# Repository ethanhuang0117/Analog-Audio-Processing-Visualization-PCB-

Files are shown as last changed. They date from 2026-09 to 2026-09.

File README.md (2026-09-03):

# Analog Audio Processing & Visualization PCB

A custom analog audio spectrum analyzer PCB that processes microphone audio across 8 frequency bands and displays signal intensity using 4-level LED indicators.

<p align="center">
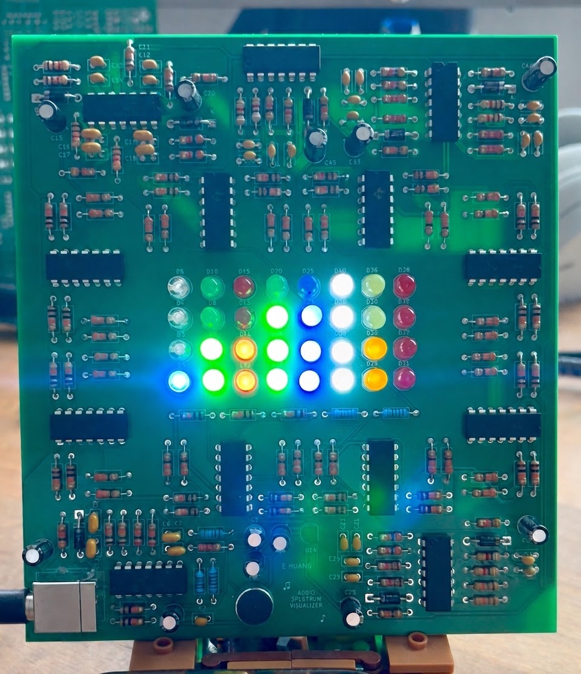
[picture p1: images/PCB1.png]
  
</p>

### Demo

[Download and Watch the PCB Demo](images/demo.mp4)

## Overview

The system captures audio through an electret microphone, amplifies the signal, separates it into 8 frequency bands using active filters, and displays the signal intensity through LED indicators.

**System Chain:**

Microphone → Preamp → 8-Band Filters → Envelope Detection → Comparators → LED Visualization

## Features

- 8 frequency bands spanning approximately 80 Hz – 10 kHz
- Cascaded Sallen-Key active filters for improved frequency separation
- Microphone preamplification for low-level audio signals
- Envelope detection to convert AC audio signals into DC levels
- 4-level LED intensity indication for each frequency band using comparators
- USB 5 V single-supply
- Custom PCB designed and assembled in KiCad

## Frequency Bands

| Band | Centre Frequency |
|---|---:|
| 1 | 80 Hz |
| 2 | 160 Hz |
| 3 | 320 Hz |
| 4 | 640 Hz |
| 5 | 1.25 kHz |
| 6 | 2.5 kHz |
| 7 | 5 kHz |
| 8 | 10 kHz |

## Filter Design

The initial design used passive filters, but were redesigned using cascaded Sallen-Key active filters to achieve greater roll-off and band separation.

<p align="center">
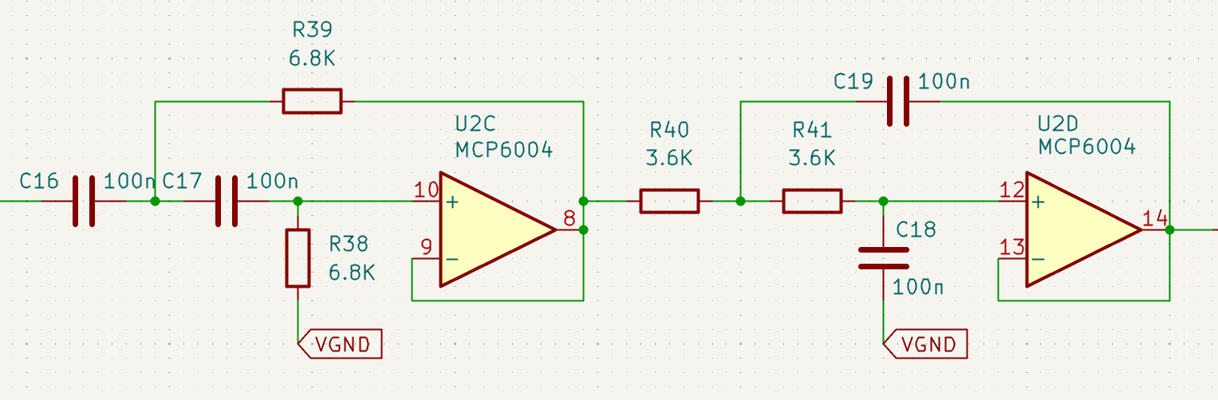
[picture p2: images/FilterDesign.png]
  
</p>

### Sallen-Key Bandpass Filter Calculations

Each frequency band consists of a cascaded 2nd order Sallen-Key High Pass Filter (HPF) and Low Pass Filter (LPF).

**Assumptions:**
- $R_1 = R_2 = R$
- $C_1 = C_2 = C$
- $C = 100\text{nF}$ (Bands 1-4), $C = 10\text{nF}$ (Bands 5-8)

The cutoff frequencies are spaced by $\sqrt{2}$ from the centre frequency.

$$f_H = f_0 \times \sqrt{2}$$

$$f_L = \frac{f_0}{\sqrt{2}}$$

The general Sallen-Key cutoff frequency formula before simplification is:

$$f = \frac{1}{2\pi\sqrt{R_1 R_2 C_1 C_2}}$$

Applying the assumptions $R_1 = R_2 = R$ and $C_1 = C_2 = C$, this simplifies to:

$$f = \frac{1}{2\pi RC}$$

Rearranging for $R$:

$$R = \frac{1}{2\pi f C}$$

---

### Band 4 Example (Centre frequency: 640Hz)

**Step 1: Calculate HPF cutoff frequency**

$$f_L = \frac{f_0}{\sqrt{2}} = \frac{640}{\sqrt{2}} = 453\text{Hz}$$

**Step 2: Calculate LPF cutoff frequency**

$$f_H = f_0 \times \sqrt{2} = 640 \times \sqrt{2} = 905\text{Hz}$$

**Step 3: Calculate HPF resistor value ($C = 100\text{nF}$)**

$$R_{HPF} = \frac{1}{2\pi \times 453 \times 100 \times 10^{-9}} = 3513\Omega \approx 3.6\text{k}\Omega$$

**Step 4: Calculate LPF resistor value ($C = 100\text{nF}$)**

$$R_{LPF} = \frac{1}{2\pi \times 905 \times 100 \times 10^{-9}} = 1759\Omega \approx 1.8\text{k}\Omega$$

---

### Filter Band Summary

| Band | Centre Frequency | C | HPF Cutoff | HPF R | LPF Cutoff | LPF R |
|---|---|---|---|---|---|---|
| 1 | 80Hz | 100nF | 56.6Hz | 27kΩ | 113Hz | 15kΩ |
| 2 | 160Hz | 100nF | 113Hz | 15kΩ | 226Hz | 6.8kΩ |
| 3 | 320Hz | 100nF | 226Hz | 6.8kΩ | 453Hz | 3.6kΩ |
| 4 | 640Hz | 100nF | 453Hz | 3.6kΩ | 905Hz | 1.8kΩ |
| 5 | 1.25kHz | 10nF | 884Hz | 18kΩ | 1.77kHz | 9.1kΩ |
| 6 | 2.5kHz | 10nF | 1.77kHz | 9.1kΩ | 3.54kHz | 4.7kΩ |
| 7 | 5kHz | 10nF | 3.54kHz | 4.7kΩ | 7.07kHz | 2.2kΩ |
| 8 | 10kHz | 10nF | 7.07kHz | 2.2kΩ | 14.1kHz | 1.1kΩ |

## Circuit Design

### Power

The circuit operates from a 5 V USB supply. Since audio signals oscillate about a center point, a virtual ground of 2.5V is used to allow the analog signal stages to operate from a single supply.

<p align="center">
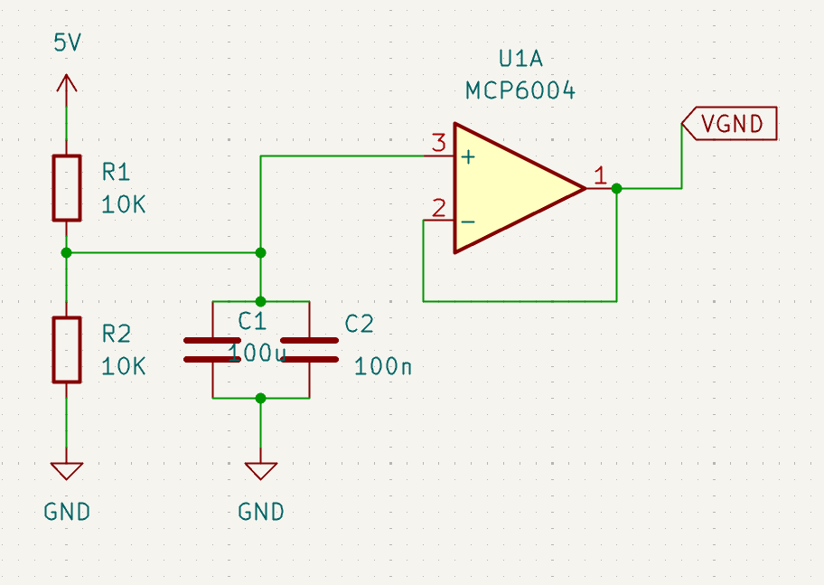
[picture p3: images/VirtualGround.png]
  
</p>

### Microphone & Preamplifier

A CMA-4544PF-W electret microphone captures the incoming audio signal, which is amplified using an MCP6004 op-amp to provide a suitable signal level for the filter stages.

The CMA-4544PF-W was chosen because its frequency response of 20Hz-20kHz covers the full audio spectrum.

<p align="center">
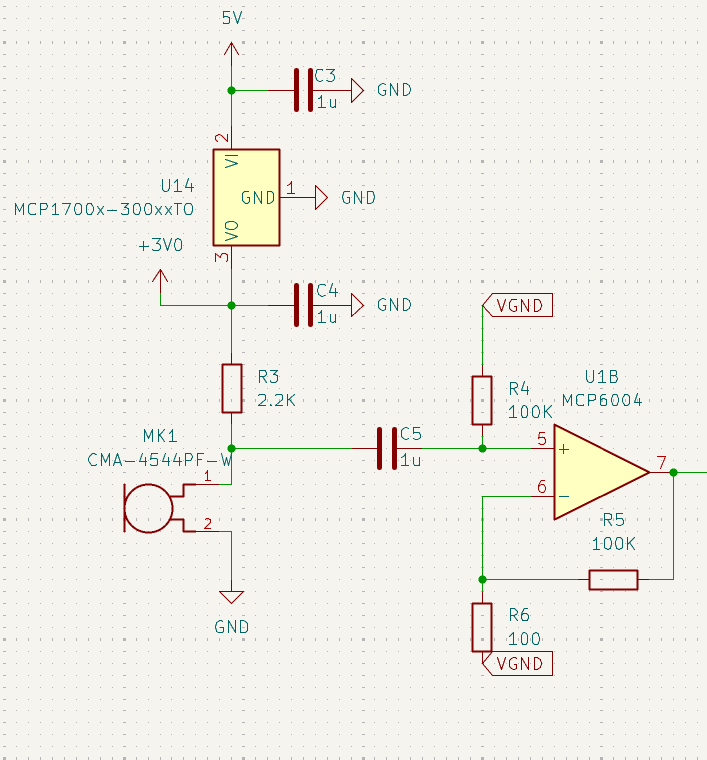
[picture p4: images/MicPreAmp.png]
  
</p>

### Envelope Detection

Each filtered signal passes through an envelope detector to convert the AC waveform into a varying DC voltage proportional to its amplitude.

<p align="center">
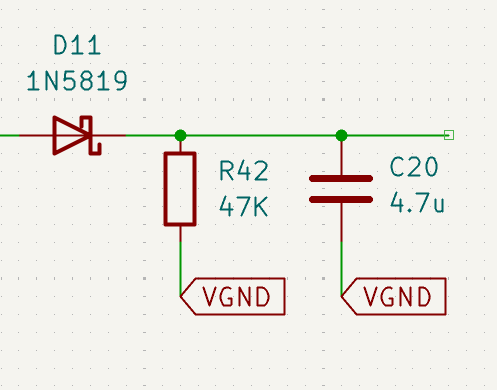
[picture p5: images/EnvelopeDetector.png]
  
</p>

The RC time constant determines the decay time of the envelope:

$$\tau = R \times C = 47\text{k}\Omega \times 4.7\mu\text{F} = 221\text{ms}$$

This gives a smooth, natural decay that visually tracks the music without flickering too fast or responding too sluggishly.

### Comparator & LED Stage

Comparator circuits divide each detected signal into four amplitude thresholds. The resulting outputs drive four LEDs per frequency band to provide a 4-level visualization of audio intensity.

## Prototyping & Testing

Individual circuit stages were first tested on breadboards and simulated in Multisim before PCB fabrication.

<p align="center">
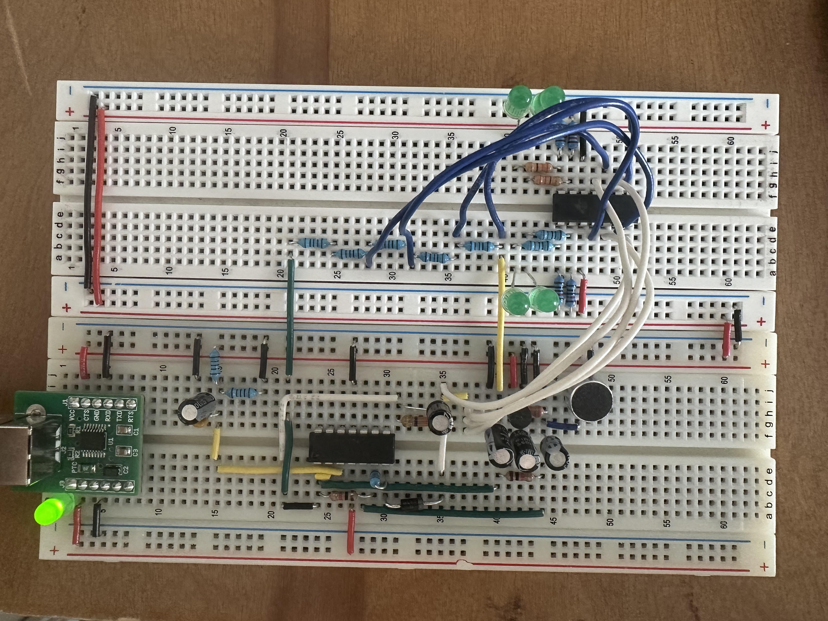
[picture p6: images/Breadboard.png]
  
</p>

This iterative testing helped identify design issues before fabrication and reduced the need for PCB rework.

## PCB Design

The validated circuit was translated into a custom PCB using KiCad, with component placement, routing, and ground pours optimized for a compact and reliable layout.

<p align="center">
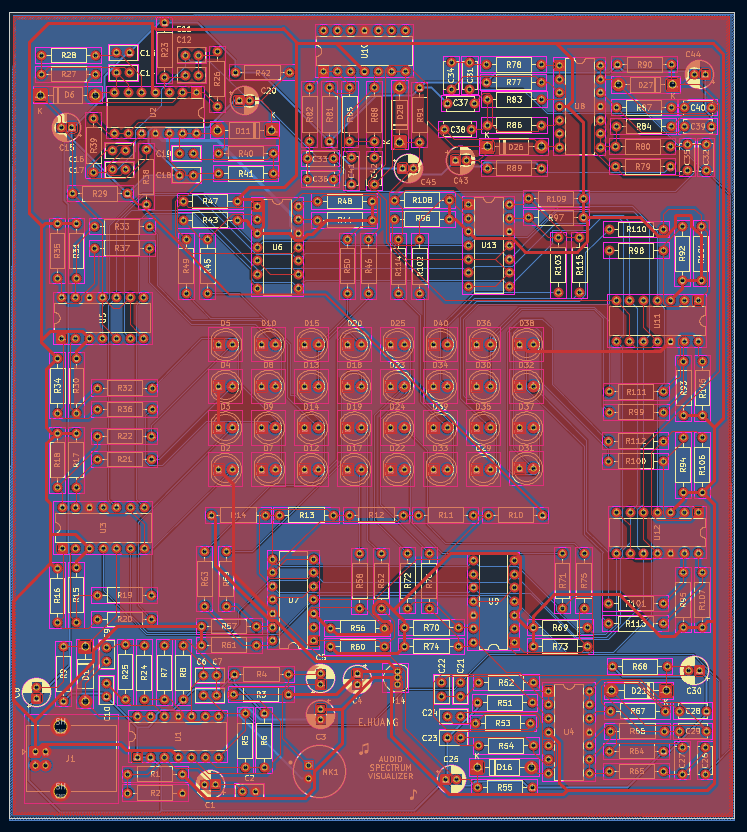
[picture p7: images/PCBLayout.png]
  
</p>

### 3D PCB View

<p align="center">
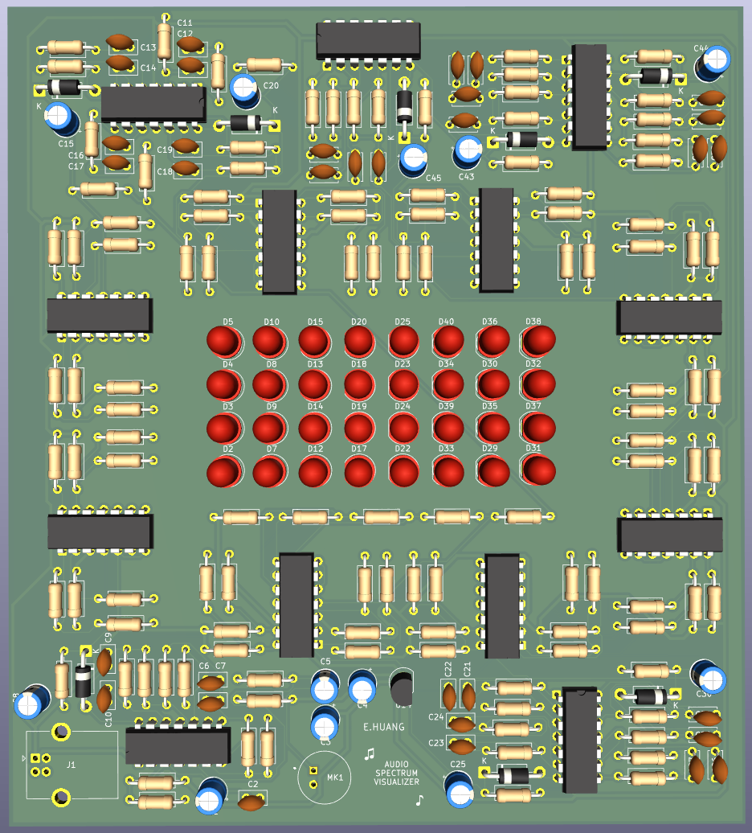
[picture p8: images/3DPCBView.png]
  
</p>

### Schematic

[View Full Schematic (PDF)](Schematic.pdf)

## Results

The completed PCB successfully processes audio through the 8 frequency bands and provides visual feedback through the LED array.

<p align="center">
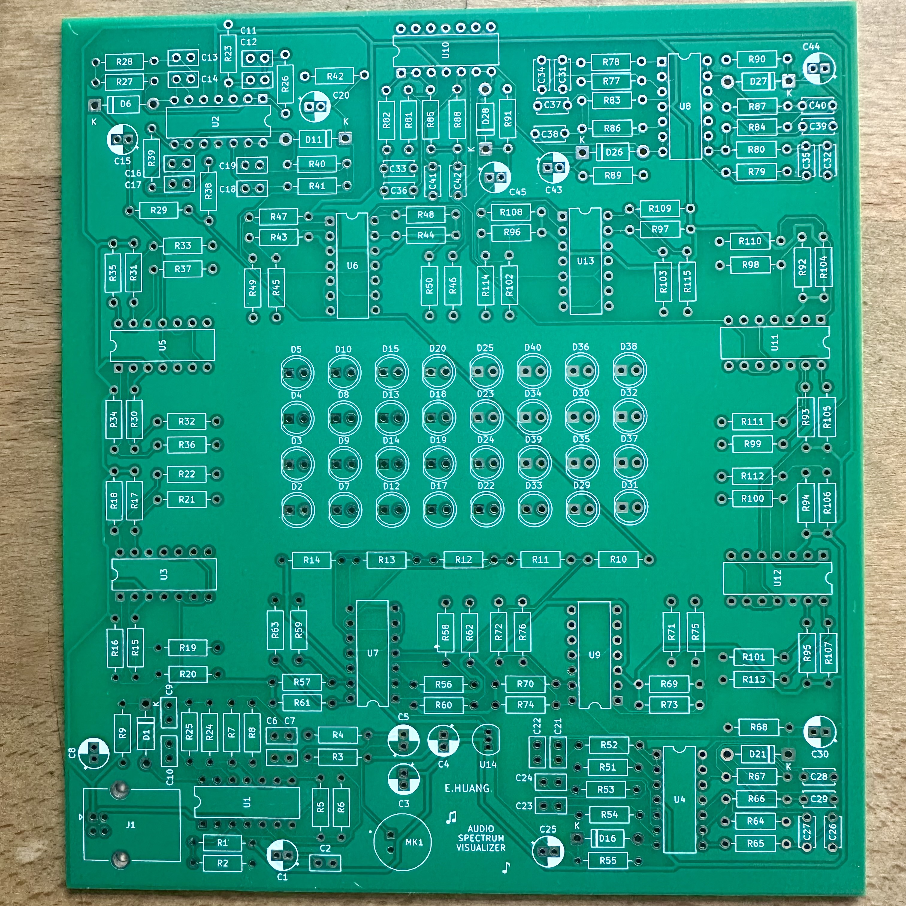
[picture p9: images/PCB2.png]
  
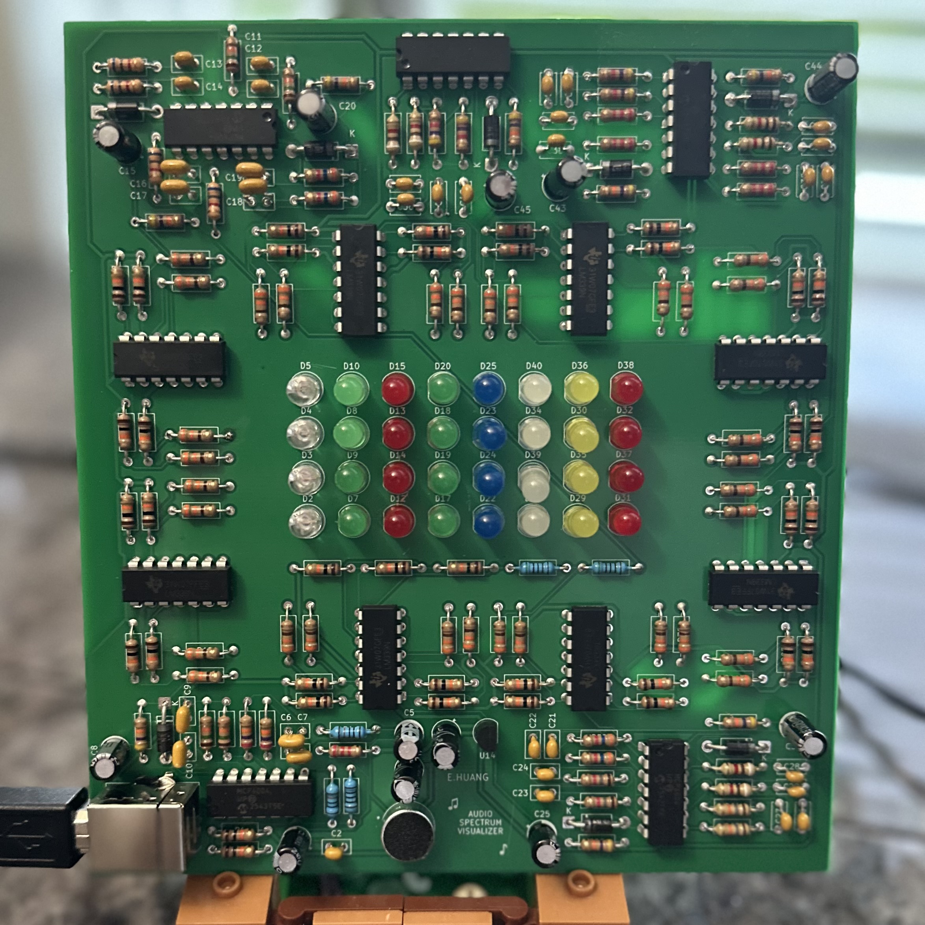
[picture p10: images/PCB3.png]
  
</p>

## Design Challenges & Iterations

### Passive → Active Filter Redesign

The original passive filter approach did not provide sufficient frequency separation. Sallen-Key active filters were implemented to improve roll-off and isolation between adjacent bands.

### Gain Optimization

The preamplifier gain was iteratively adjusted during breadboard testing to provide sufficient signal amplitude without excessive amplification of noise.

### Single-Supply Operation

Because the circuit operates from a 5 V USB supply, a virtual ground was implemented to allow the op-amp stages to process audio signals within the available supply range.

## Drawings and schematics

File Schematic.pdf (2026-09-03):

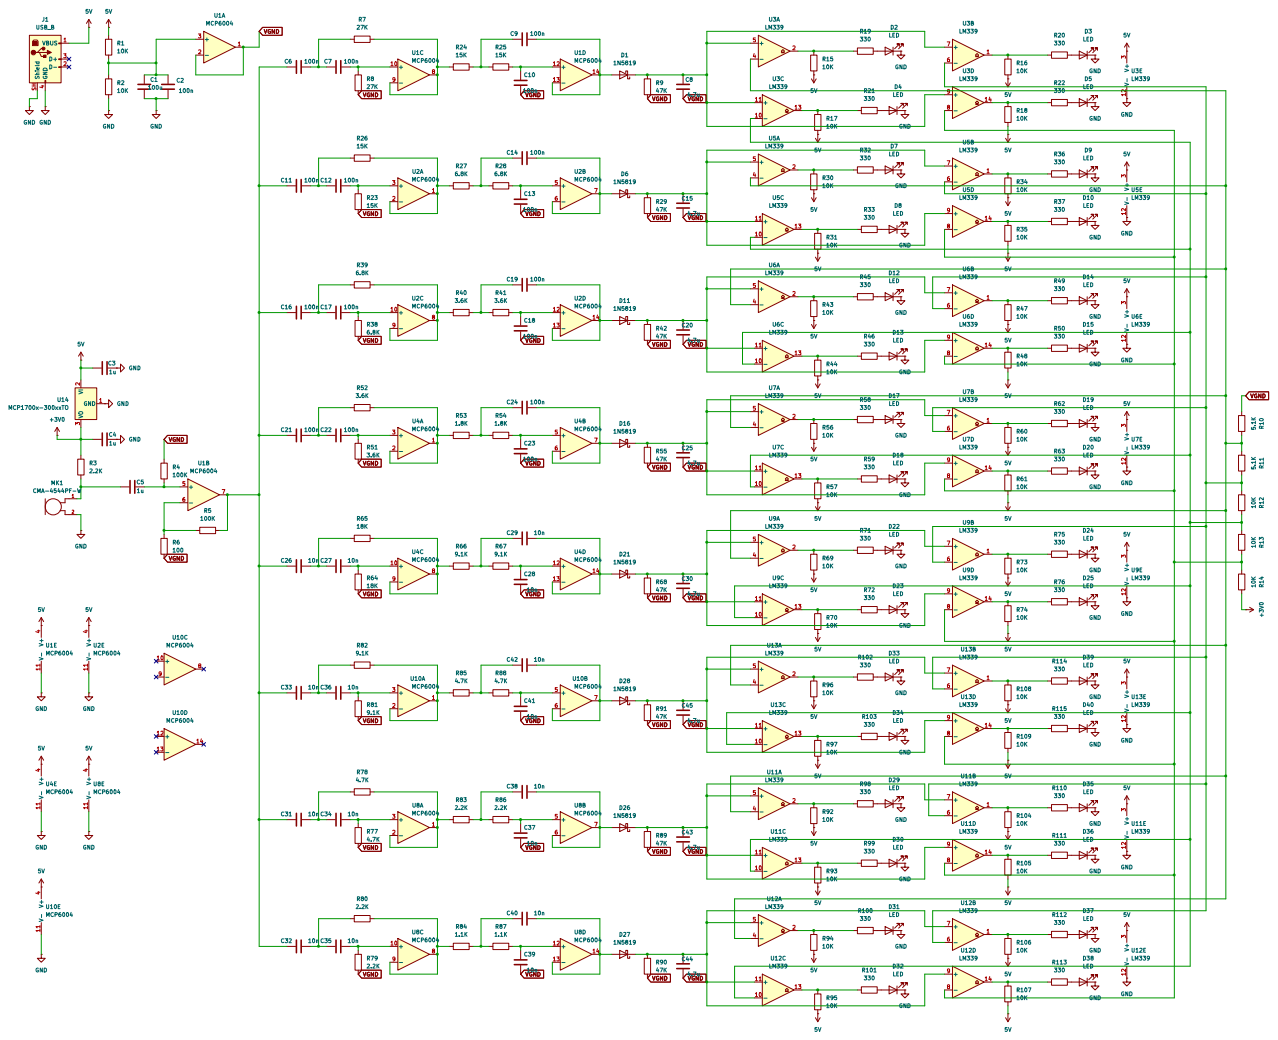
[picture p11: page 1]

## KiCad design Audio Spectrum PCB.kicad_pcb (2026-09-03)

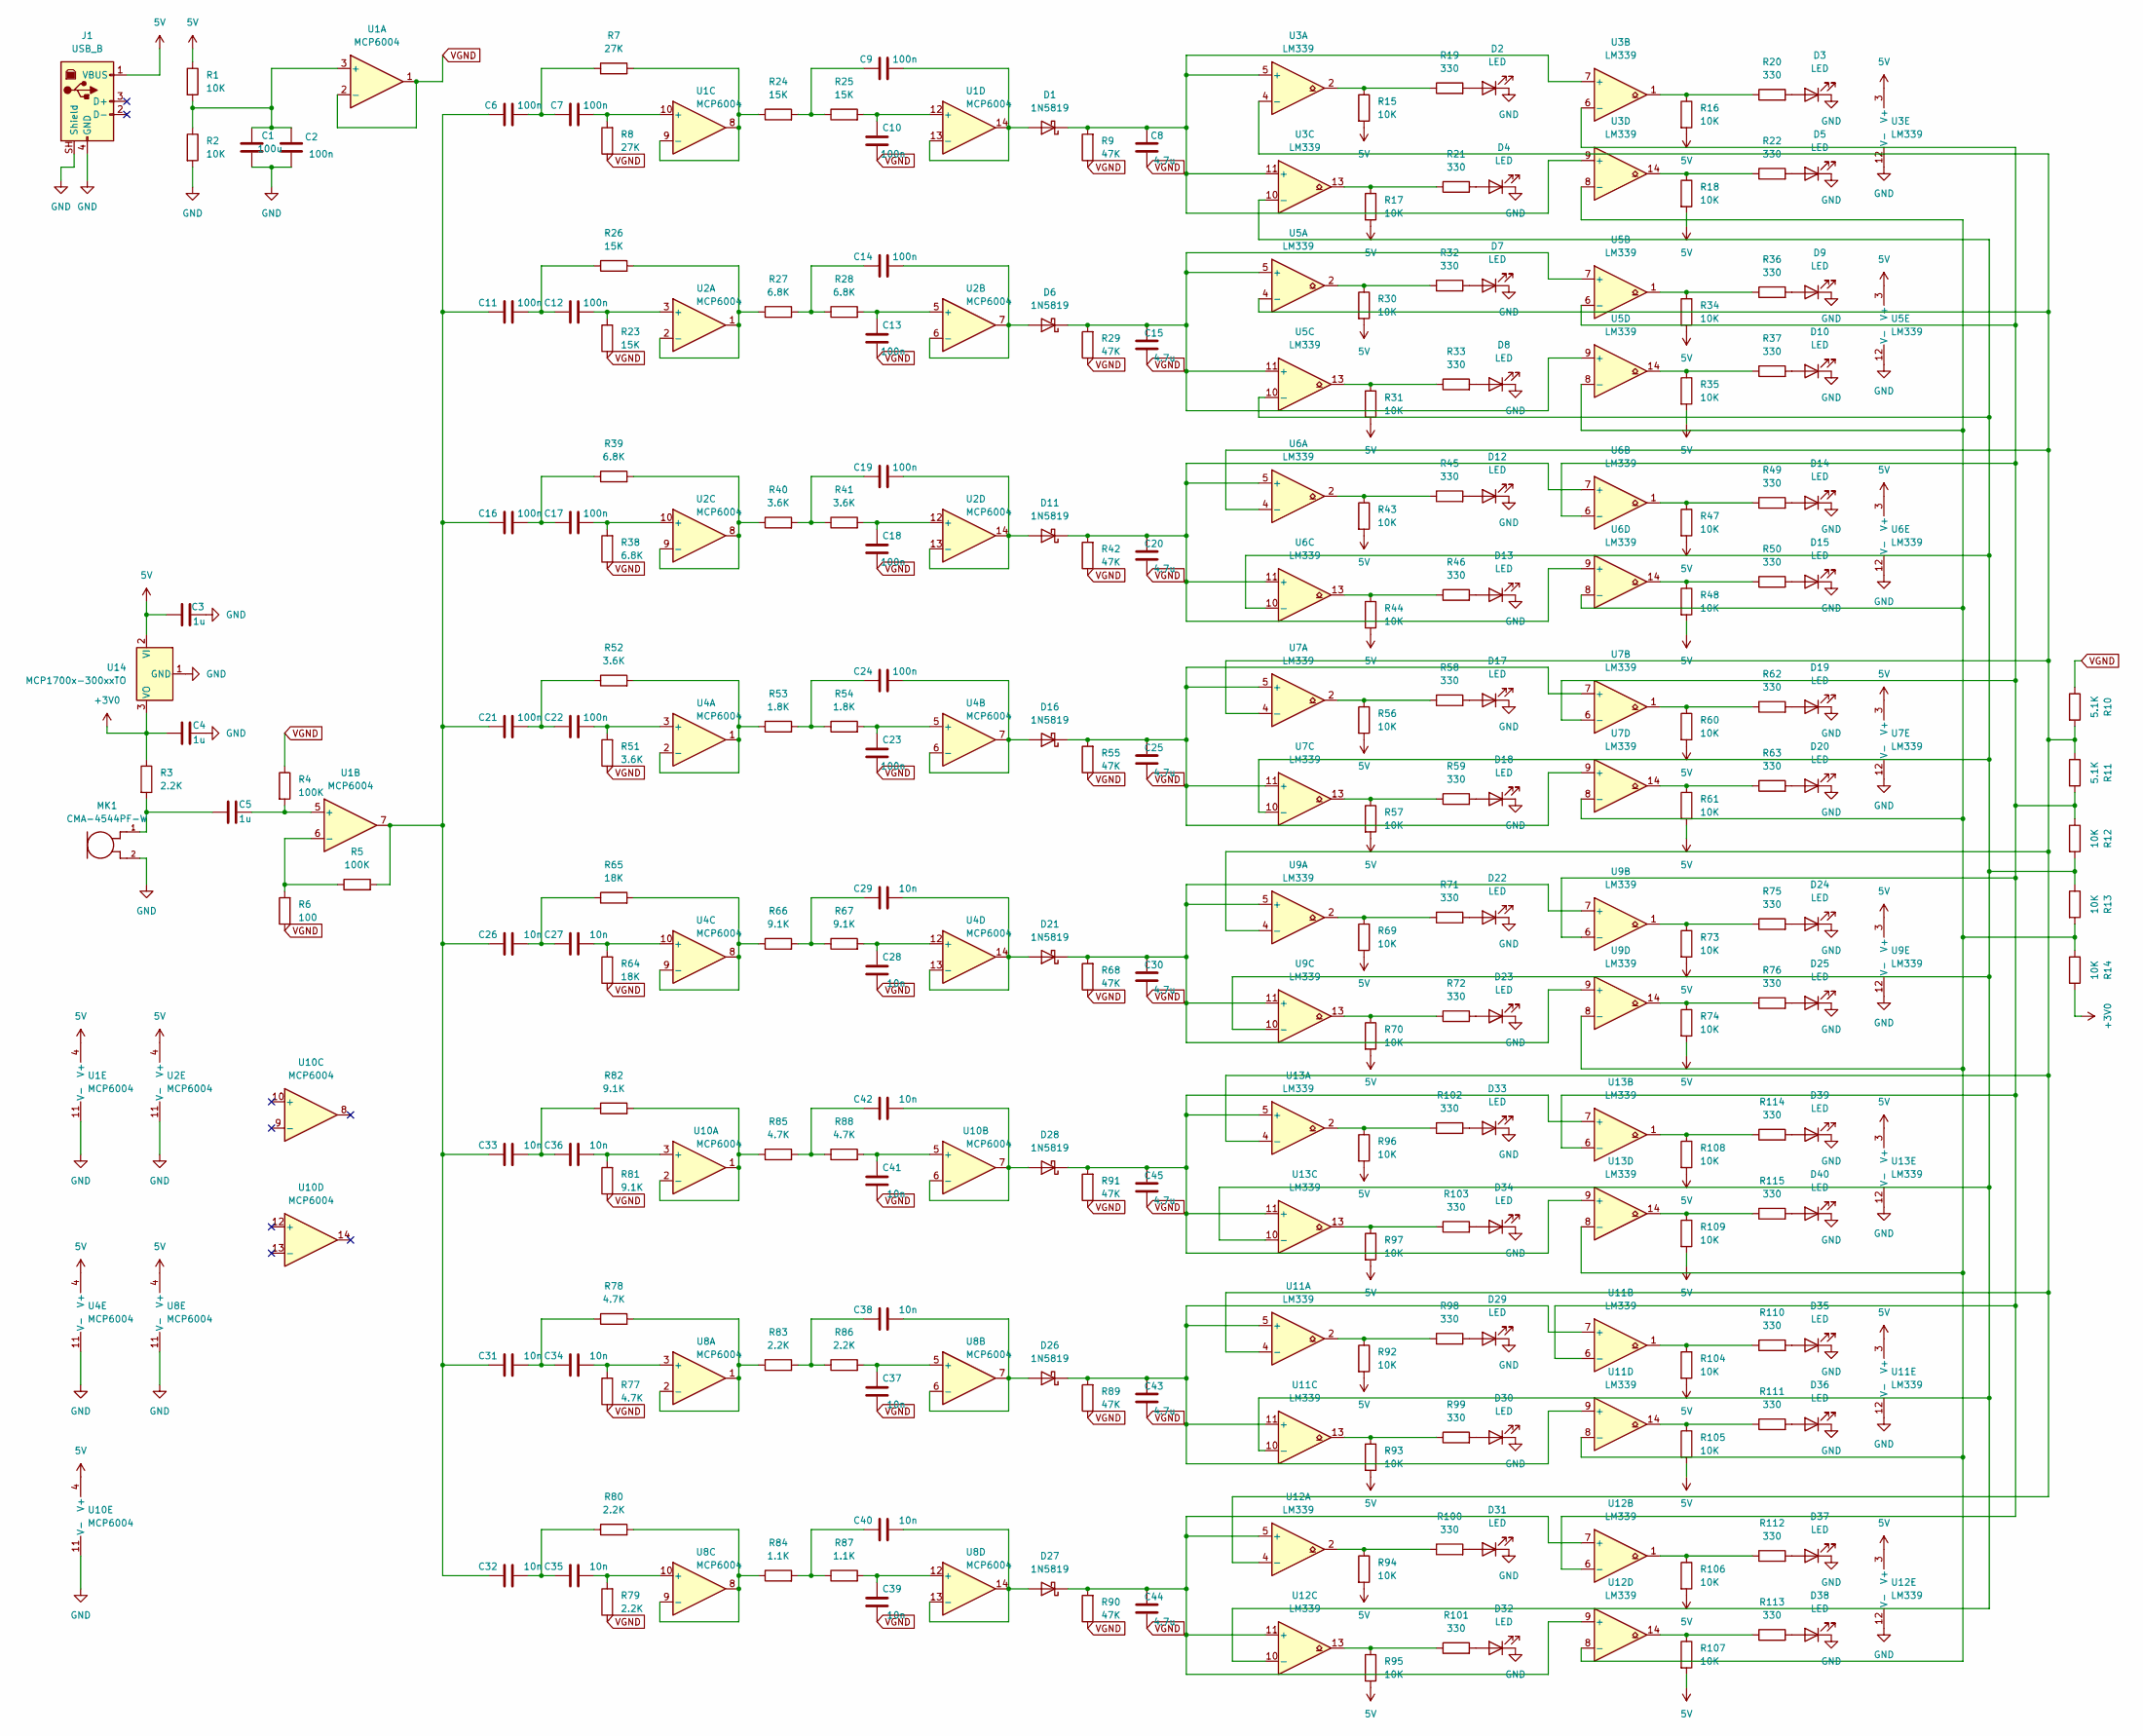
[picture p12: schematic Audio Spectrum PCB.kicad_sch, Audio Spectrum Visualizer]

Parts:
C1: 100u; CP_Radial_D5.0mm_P2.00mm
C2, C6, C7, C9, C10, C11, C12, C13, C14, C16, C17, C18, C19, C21, C22, C23, C24: 100n; C_Disc_D5.0mm_W2.5mm_P2.50mm
C3, C4, C5: 1u; CP_Radial_D5.0mm_P2.00mm
C8, C15, C20, C25, C30, C43, C44, C45: 4.7u; CP_Radial_D5.0mm_P2.00mm
C26, C27, C28, C29, C31, C32, C33, C34, C35, C36, C37, C38, C39, C40, C41, C42: 10n; C_Disc_D5.0mm_W2.5mm_P5.00mm
D1, D6, D11, D16, D21, D26, D27, D28: 1N5819; D_DO-41_SOD81_P10.16mm_Horizontal
D2, D3, D4, D5, D7, D8, D9, D10, D12, D13, D14, D15, D17, D18, D19, D20, D22, D23, D24, D25, D29, D30, D31, D32, D33, D34, D35, D36, D37, D38, D39, D40: LED; LED_D5.0mm
J1: USB_B; USB_B_OST_USB-B1HSxx_Horizontal
MK1: CMA-4544PF-W; MIC_CMA-4544PF-W
R1, R2, R12, R13, R14, R15, R16, R17, R18, R30, R31, R34, R35, R43, R44, R47, R48, R56, R57, R60, R61, R69, R70, R73, R74, R92, R93, R94, R95, R96, R97, R104, R105, R106, R107, R108, R109: 10K; R_Axial_DIN0207_L6.3mm_D2.5mm_P10.16mm_Horizontal
R3, R79, R80, R83, R86: 2.2K; R_Axial_DIN0207_L6.3mm_D2.5mm_P10.16mm_Horizontal
R4, R5: 100K; R_Axial_DIN0207_L6.3mm_D2.5mm_P10.16mm_Horizontal
R6: 100; R_Axial_DIN0207_L6.3mm_D2.5mm_P10.16mm_Horizontal
R7, R8: 27K; R_Axial_DIN0207_L6.3mm_D2.5mm_P10.16mm_Horizontal
R9, R29, R42, R55, R68, R89, R90, R91: 47K; R_Axial_DIN0207_L6.3mm_D2.5mm_P10.16mm_Horizontal
R10, R11: 5.1K; R_Axial_DIN0207_L6.3mm_D2.5mm_P10.16mm_Horizontal
R19, R20, R21, R22, R32, R33, R36, R37, R45, R46, R49, R50, R58, R59, R62, R63, R71, R72, R75, R76, R98, R99, R100, R101, R102, R103, R110, R111, R112, R113, R114, R115: 330; R_Axial_DIN0207_L6.3mm_D2.5mm_P10.16mm_Horizontal
R23, R24, R25, R26: 15K; R_Axial_DIN0207_L6.3mm_D2.5mm_P10.16mm_Horizontal
R27, R28, R38, R39: 6.8K; R_Axial_DIN0207_L6.3mm_D2.5mm_P10.16mm_Horizontal
R40, R41, R51, R52: 3.6K; R_Axial_DIN0207_L6.3mm_D2.5mm_P10.16mm_Horizontal
R53, R54: 1.8K; R_Axial_DIN0207_L6.3mm_D2.5mm_P10.16mm_Horizontal
R64, R65: 18K; R_Axial_DIN0207_L6.3mm_D2.5mm_P10.16mm_Horizontal
R66, R67, R81, R82: 9.1K; R_Axial_DIN0207_L6.3mm_D2.5mm_P10.16mm_Horizontal
R77, R78, R85, R88: 4.7K; R_Axial_DIN0207_L6.3mm_D2.5mm_P10.16mm_Horizontal
R84, R87: 1.1K; R_Axial_DIN0207_L6.3mm_D2.5mm_P10.16mm_Horizontal
U1, U2, U4, U8, U10: MCP6004; DIP-14_W7.62mm
U3, U5, U6, U7, U9, U11, U12, U13: LM339; DIP-14_W7.62mm
U14: MCP1700x-300xxTO; TO-92_Inline

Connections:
5V: C3.1, J1.1 (VBUS), R1.1, R15.2, R16.2, R17.2, R18.2, R30.2, R31.2, R34.2, R35.2, R43.2, R44.2, R47.2, R48.2, R56.2, R57.2, R60.2, R61.2, R69.2, R70.2, R73.2, R74.2, R92.2, R93.2, R94.2, R95.2, R96.2, R97.2, R104.2, R105.2, R106.2, R107.2, R108.2, R109.2, U1.4 (V+), U2.4 (V+), U3.3 (V+), U4.4 (V+), U5.3 (V+), U6.3 (V+), U7.3 (V+), U8.4 (V+), U9.3 (V+), U10.4 (V+), U11.3 (V+), U12.3 (V+), U13.3 (V+), U14.2 (VI)
+3V0: C4.1, R3.1, R14.2, U14.3 (VO)
GND: C1.2, C2.2, C3.2, C4.2, D2.1 (K), D3.1 (K), D4.1 (K), D5.1 (K), D7.1 (K), D8.1 (K), D9.1 (K), D10.1 (K), D12.1 (K), D13.1 (K), D14.1 (K), D15.1 (K), D17.1 (K), D18.1 (K), D19.1 (K), D20.1 (K), D22.1 (K), D23.1 (K), D24.1 (K), D25.1 (K), D29.1 (K), D30.1 (K), D31.1 (K), D32.1 (K), D33.1 (K), D34.1 (K), D35.1 (K), D36.1 (K), D37.1 (K), D38.1 (K), D39.1 (K), D40.1 (K), J1.4 (GND), J1.SH (Shield), MK1.2, R2.2, U1.11 (V-), U2.11 (V-), U3.12 (V-), U4.11 (V-), U5.12 (V-), U6.12 (V-), U7.12 (V-), U8.11 (V-), U9.12 (V-), U10.11 (V-), U11.12 (V-), U12.12 (V-), U13.12 (V-), U14.1 (GND)
unnamed: C5.1, MK1.1, R3.2
unnamed: C6.2, C7.1, R7.1
unnamed: C9.1, R24.2, R25.1
unnamed: C6.1, C11.1, C16.1, C21.1, C26.1, C31.1, C32.1, C33.1, R5.2, U1.7
unnamed: C11.2, C12.1, R26.1
unnamed: C14.1, R27.2, R28.1
unnamed: C16.2, C17.1, R39.1
unnamed: C19.1, R40.2, R41.1
unnamed: C21.2, C22.1, R52.1
unnamed: C24.1, R53.2, R54.1
unnamed: C26.2, C27.1, R65.1
unnamed: C29.1, R66.2, R67.1
unnamed: C31.2, C34.1, R78.1
unnamed: C32.2, C35.1, R80.1
unnamed: C33.2, C36.1, R82.1
unnamed: C38.1, R83.2, R86.1
unnamed: C40.1, R84.2, R87.1
unnamed: C42.1, R85.2, R88.1
unnamed: C9.2, D1.2 (A), U1.13 (-), U1.14
unnamed: C8.2, D1.1 (K), R9.2, U3.5 (+), U3.7 (+), U3.9 (+), U3.11 (+)
unnamed: D2.2 (A), R19.2
unnamed: D3.2 (A), R20.2
unnamed: D4.2 (A), R21.2
unnamed: D5.2 (A), R22.2
unnamed: C14.2, D6.2 (A), U2.6 (-), U2.7
unnamed: C15.2, D6.1 (K), R29.2, U5.5 (+), U5.7 (+), U5.9 (+), U5.11 (+)
unnamed: D7.2 (A), R32.2
unnamed: D8.2 (A), R33.2
unnamed: D9.2 (A), R36.2
unnamed: D10.2 (A), R37.2
unnamed: C19.2, D11.2 (A), U2.13 (-), U2.14
unnamed: C20.2, D11.1 (K), R42.2, U6.5 (+), U6.7 (+), U6.9 (+), U6.11 (+)
unnamed: D12.2 (A), R45.2
unnamed: D13.2 (A), R46.2
unnamed: D14.2 (A), R49.2
unnamed: D15.2 (A), R50.2
unnamed: C24.2, D16.2 (A), U4.6 (-), U4.7
unnamed: C25.2, D16.1 (K), R55.2, U7.5 (+), U7.7 (+), U7.9 (+), U7.11 (+)
unnamed: D17.2 (A), R58.2
unnamed: D18.2 (A), R59.2
unnamed: D19.2 (A), R62.2
unnamed: D20.2 (A), R63.2
unnamed: C29.2, D21.2 (A), U4.13 (-), U4.14
unnamed: C30.2, D21.1 (K), R68.2, U9.5 (+), U9.7 (+), U9.9 (+), U9.11 (+)
unnamed: D22.2 (A), R71.2
unnamed: D23.2 (A), R72.2
unnamed: D24.2 (A), R75.2
unnamed: D25.2 (A), R76.2
unnamed: C38.2, D26.2 (A), U8.6 (-), U8.7
unnamed: C43.2, D26.1 (K), R89.2, U11.5 (+), U11.7 (+), U11.9 (+), U11.11 (+)
unnamed: C40.2, D27.2 (A), U8.13 (-), U8.14
unnamed: C44.2, D27.1 (K), R90.2, U12.5 (+), U12.7 (+), U12.9 (+), U12.11 (+)
unnamed: C42.2, D28.2 (A), U10.6 (-), U10.7
unnamed: C45.2, D28.1 (K), R91.2, U13.5 (+), U13.7 (+), U13.9 (+), U13.11 (+)
unnamed: D29.2 (A), R98.2
unnamed: D30.2 (A), R99.2
unnamed: D31.2 (A), R100.2
unnamed: D32.2 (A), R101.2
unnamed: D33.2 (A), R102.2
unnamed: D34.2 (A), R103.2
unnamed: D35.2 (A), R110.2
unnamed: D36.2 (A), R111.2
unnamed: D37.2 (A), R112.2
unnamed: D38.2 (A), R113.2
unnamed: D39.2 (A), R114.2
unnamed: D40.2 (A), R115.2
unnamed: R15.1, R19.1, U3.2
unnamed: R16.1, R20.1, U3.1
unnamed: R17.1, R21.1, U3.13
unnamed: R18.1, R22.1, U3.14
unnamed: R30.1, R32.1, U5.2
unnamed: R31.1, R33.1, U5.13
unnamed: R34.1, R36.1, U5.1
unnamed: R35.1, R37.1, U5.14
unnamed: R43.1, R45.1, U6.2
unnamed: R44.1, R46.1, U6.13
unnamed: R47.1, R49.1, U6.1
unnamed: R48.1, R50.1, U6.14
unnamed: R56.1, R58.1, U7.2
unnamed: R57.1, R59.1, U7.13
unnamed: R60.1, R62.1, U7.1
unnamed: R61.1, R63.1, U7.14
unnamed: R69.1, R71.1, U9.2
unnamed: R70.1, R72.1, U9.13
unnamed: R73.1, R75.1, U9.1
unnamed: R74.1, R76.1, U9.14
unnamed: R92.1, R98.1, U11.2
unnamed: R93.1, R99.1, U11.13
unnamed: R94.1, R100.1, U12.2
unnamed: R95.1, R101.1, U12.13
unnamed: R96.1, R102.1, U13.2
unnamed: R97.1, R103.1, U13.13
unnamed: R104.1, R110.1, U11.1
unnamed: R105.1, R111.1, U11.14
unnamed: R106.1, R112.1, U12.1
unnamed: R107.1, R113.1, U12.14
unnamed: R108.1, R114.1, U13.1
unnamed: R109.1, R115.1, U13.14
unnamed: C1.1, C2.1, R1.2, R2.1, U1.3 (+)
unnamed: C5.2, R4.2, U1.5 (+)
unnamed: R5.1, R6.2, U1.6 (-)
unnamed: C7.2, R8.2, U1.10 (+)
unnamed: R7.2, R24.1, U1.8, U1.9 (-)
unnamed: C10.2, R25.2, U1.12 (+)
unnamed: C12.2, R23.2, U2.3 (+)
unnamed: R26.2, R27.1, U2.1, U2.2 (-)
unnamed: C13.2, R28.2, U2.5 (+)
unnamed: C17.2, R38.2, U2.10 (+)
unnamed: R39.2, R40.1, U2.8, U2.9 (-)
unnamed: C18.2, R41.2, U2.12 (+)
unnamed: C22.2, R51.2, U4.3 (+)
unnamed: R52.2, R53.1, U4.1, U4.2 (-)
unnamed: C23.2, R54.2, U4.5 (+)
unnamed: C27.2, R64.2, U4.10 (+)
unnamed: R65.2, R66.1, U4.8, U4.9 (-)
unnamed: C28.2, R67.2, U4.12 (+)
unnamed: C34.2, R77.2, U8.3 (+)
unnamed: R78.2, R83.1, U8.1, U8.2 (-)
unnamed: C37.2, R86.2, U8.5 (+)
unnamed: C35.2, R79.2, U8.10 (+)
unnamed: R80.2, R84.1, U8.8, U8.9 (-)
unnamed: C39.2, R87.2, U8.12 (+)
unnamed: C36.2, R81.2, U10.3 (+)
unnamed: R82.2, R85.1, U10.1, U10.2 (-)
unnamed: C41.2, R88.2, U10.5 (+)
unnamed: R10.2, R11.1, U3.4 (-), U5.4 (-), U6.4 (-), U7.4 (-), U9.4 (-), U11.4 (-), U12.4 (-), U13.4 (-)
unnamed: R11.2, R12.1, U3.6 (-), U5.6 (-), U6.6 (-), U7.6 (-), U9.6 (-), U11.6 (-), U12.6 (-), U13.6 (-)
unnamed: R12.2, R13.1, U3.10 (-), U5.10 (-), U6.10 (-), U7.10 (-), U9.10 (-), U11.10 (-), U12.10 (-), U13.10 (-)
unnamed: R13.2, R14.1, U3.8 (-), U5.8 (-), U6.8 (-), U7.8 (-), U9.8 (-), U11.8 (-), U12.8 (-), U13.8 (-)
VGND: C8.1, C10.1, C13.1, C15.1, C18.1, C20.1, C23.1, C25.1, C28.1, C30.1, C37.1, C39.1, C41.1, C43.1, C44.1, C45.1, R4.1, R6.1, R8.1, R9.1, R10.1, R23.1, R29.1, R38.1, R42.1, R51.1, R55.1, R64.1, R68.1, R77.1, R79.1, R81.1, R89.1, R90.1, R91.1, U1.1, U1.2 (-)

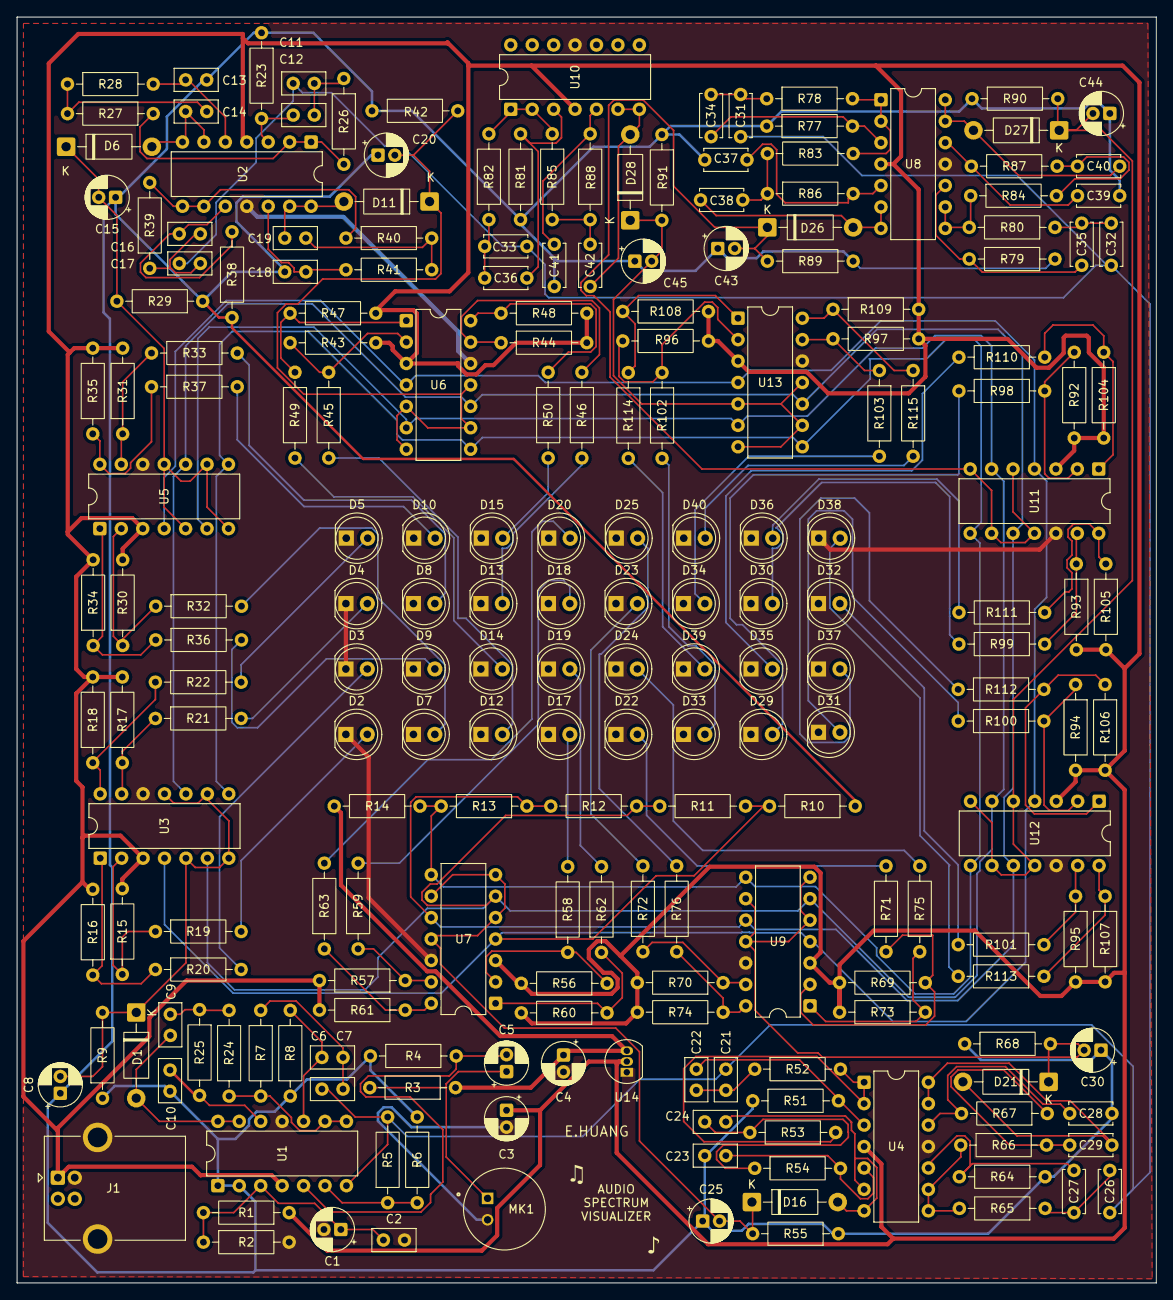
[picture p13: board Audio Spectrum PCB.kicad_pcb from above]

Board: 2 copper layers, 135.0 x 150.0 mm, 216 parts (0 on the bottom side), 133 nets.
